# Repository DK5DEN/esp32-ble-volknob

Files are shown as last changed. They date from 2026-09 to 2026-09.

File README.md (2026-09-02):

# ESP32 BLE Volume Knob

A rotary knob based on the **ESP32-C3 Super Mini** that registers with an
Android phone over Bluetooth LE as an HID media keyboard ("VolKnob") and
controls the media volume.

- **Turn clockwise** → `KEY_MEDIA_VOLUME_UP`
- **Turn counter-clockwise** → `KEY_MEDIA_VOLUME_DOWN`
- **Press the button** → `KEY_MEDIA_MUTE`

No app is required on the phone; Android handles the HID consumer control
codes natively. The ESP32-C3 is powered over USB-C.

## Requirements

- ESP32-C3 Super Mini (or any other C3 board with native USB Serial/JTAG)
- **KY-040** rotary encoder with push-button (4 quadrature steps per detent)
- 5 wires; optionally 3× 10 nF for hardware debouncing and 1× 100 nF for
  supply decoupling
- [PlatformIO](https://platformio.org/) to build

## Wiring

| KY-040 | ESP32-C3 |
| --- | --- |
| CLK | GPIO1 |
| DT | GPIO3 |
| SW | GPIO4 |
| + | **3V3** |
| GND | GND |

**Why CLK goes to GPIO1 and not GPIO2.** The KY-040 header `CLK·DT·SW·+·GND`
lines up exactly with pads 2–6 of the right rail (GND, 3V3, GPIO4, GPIO3,
GPIO2), the only position where GND and 3V3 are adjacent and therefore the
only orientation that can be soldered on directly. That places CLK on GPIO2,
which is a strapping pin: if the knob rests between two detents at power-up,
the CLK contact pulls GPIO2 low and the board does not boot. A pull-up strong
enough to hold GPIO2 high at boot also makes the encoder signal unreadable in
normal operation, so CLK is wired to GPIO1 (pad 7) instead and GPIO2 is left
unused.

Also leave `GPIO9` (BOOT) and `GPIO8` (LED) unused.

**Supply from 3.3 V, not 5 V.** The 10 kΩ pull-ups of the KY-040 are tied to
the module's `+` pin, so a 5 V supply would put 5 V on the C3 GPIOs. Leave the
5V pin unconnected. The firmware still configures `INPUT_PULLUP` because not
every KY-040 variant has a module pull-up on `SW`.

**Keep the antenna clear.** The antenna of the Super Mini sits at the end
opposite the USB-C connector. Do not place the encoder board over it; doing so
reduces BLE range.

### Schematic

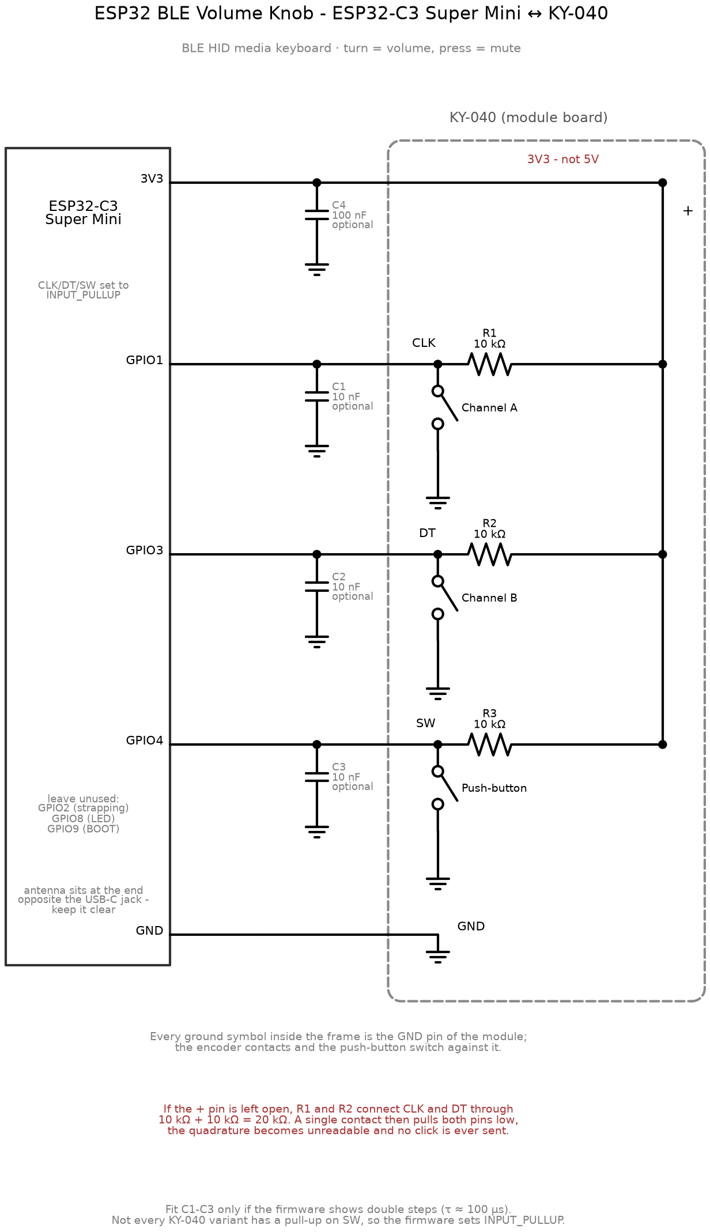
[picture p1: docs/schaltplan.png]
Schematic


The drawing also shows the internals of the KY-040 module board: R1–R3 are the
pull-ups **on the module**, tied to its `+` pin. The encoder contacts and the
push-button switch against the module's GND pin, which is why every ground
symbol inside the dashed frame is the same connection.

C1–C3 (10 nF) are optional hardware debouncing: build without them first and
only add them if the firmware shows double steps. Together with the 10 kΩ
module pull-up they give τ ≈ 100 µs. C4 (100 nF) decouples the module supply.

The drawing is generated from [`docs/schaltplan.py`](docs/schaltplan.py) using
[schemdraw](https://schemdraw.readthedocs.io/):

```bash
python docs/schaltplan.py     # writes docs/schaltplan.svg + .png
```

## Build and flash

```bash
pio run              # build
pio run -t upload    # flash
```

The C3 Super Mini enumerates as a serial port over USB Serial/JTAG
(VID `303A` / PID `1001`); no BOOT button is needed. The upload port can be
pinned down in `platformio.ini` if several boards are attached.

Footprint: roughly 500 kB of flash out of 3.1 MB (partition scheme `huge_app`)
and just under 24 kB of RAM.

The BLE HID layer comes from
[T-vK/ESP32-BLE-Keyboard](https://github.com/T-vK/ESP32-BLE-Keyboard) in its
**NimBLE flavour** (`-DUSE_NIMBLE`); the Bluedroid version quickly exceeds the
available flash on the C3.

## Pairing

Android → Bluetooth → select "VolKnob" → connect. No PIN.

## Troubleshooting

### Nothing happens even though the encoder turns mechanically

The most likely cause is that the **`+` wire (3V3) has no contact**. The
symptoms look like a firmware bug but are a wiring fault:

- CLK and DT always change *together*, only 1–2 µs apart in a microsecond
  trace, which is mechanically impossible.
- The quadrature table therefore sees the transition `11 → 00`, which is index
  3 and index 12, both `0`. Every step is discarded, `encDelta` stops moving,
  and no click is ever sent.
- On top of that, dozens of microsecond-scale edges appear per detent.

Reason: the two 10 kΩ pull-ups of the module are tied to the `+` node. If that
node floats, they connect CLK and DT through 10 k + 10 k = **20 kΩ**. When a
contact pulls CLK to ground, DT is dragged along through those 20 kΩ against
the C3's internal 45 kΩ pull-up:

```
U_DT = 3.3 V × 20k / (20k + 45k) ≈ 1.0 V   → below the logic threshold → reads 0
```

### Checking the module supply without a multimeter

Read the pin twice, once with the internal pull-up and once with the internal
pull-down:

```cpp
pinMode(pin, INPUT_PULLUP);   delayMicroseconds(500); int up   = digitalRead(pin);
pinMode(pin, INPUT_PULLDOWN); delayMicroseconds(500); int down = digitalRead(pin);
pinMode(pin, INPUT_PULLUP);
```

| pull-up | pull-down | meaning |
| --- | --- | --- |
| 1 | 1 | external pull-up present — module is connected to 3V3 |
| 1 | 0 | floating — **no** external pull-up |
| 0 | 0 | tied to ground — contact closed |

The internal pull-down is around 45 kΩ, so the 10 kΩ module pull-up wins
clearly against it. This shows whether the supply actually reaches the module
without needing a meter.

### Observing the events on the Android device

```bash
adb shell dumpsys bluetooth_manager | grep -A3 VolKnob   # bond state and Hogp profile
adb shell getevent -p | grep -A6 VolKnob                 # HID device, e.g. /dev/input/event8
adb shell settings get system volume_music               # 0..15
adb logcat -v time | grep "applyVolumeRow 3:"            # LEVEL/MUTED per change
```

Redirecting `getevent -lt` through `adb shell` into a file does not work; the
output is buffered and never arrives. `logcat` and `settings get` are the
reliable way.

### Other pitfalls

- **Verify the module pinout.** There are KY-040 variants with
  `GND·+·SW·DT·CLK` and other orders. With 3.3 V wired straight to the module,
  a swap is not forgiving.
- **Direction inverted:** swap `PIN_CLK` and `PIN_DT` in the code.
- **Double steps per detent:** set `DETENT_STEPS` to 2 or 1, depending on the
  detent scheme of the specific encoder.
- **Mute has no effect:** some Android versions ignore `KEY_MEDIA_MUTE` for the
  media stream. Fallback: track the volume on the ESP32, ramp it to 0 on the
  first press and back up on the second. On a Galaxy A16 (SM-A165F)
  `KEY_MEDIA_MUTE` works directly.
- **Reconnecting after the phone locks** takes a few seconds, which is normal
  for BLE.
- Turning while the phone is still establishing the connection has no effect;
  there is no wakelock.

## Tested with

ESP32-C3 Super Mini, KY-040, Samsung Galaxy A16 (SM-A165F): 5 detents
clockwise raise the media volume from 7 to 12, 5 detents back return it to 7,
one step per detent with no dropped clicks.

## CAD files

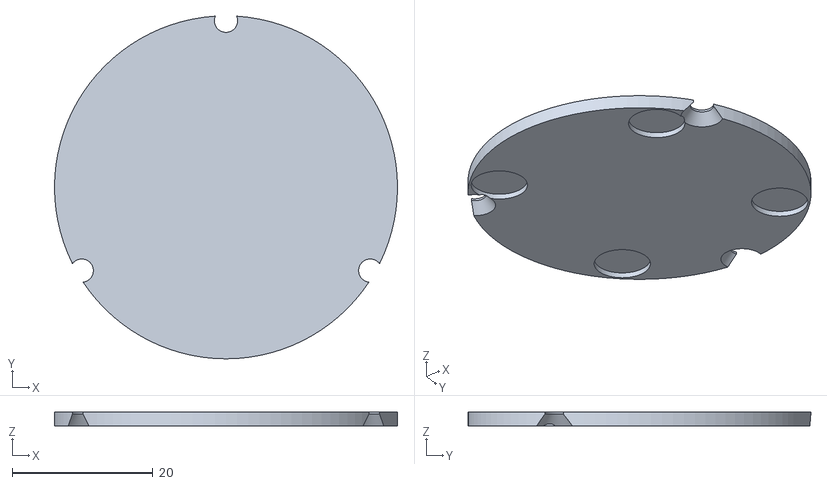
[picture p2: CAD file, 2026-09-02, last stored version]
case/plate.stl
48.8 x 48.7 x 2.00

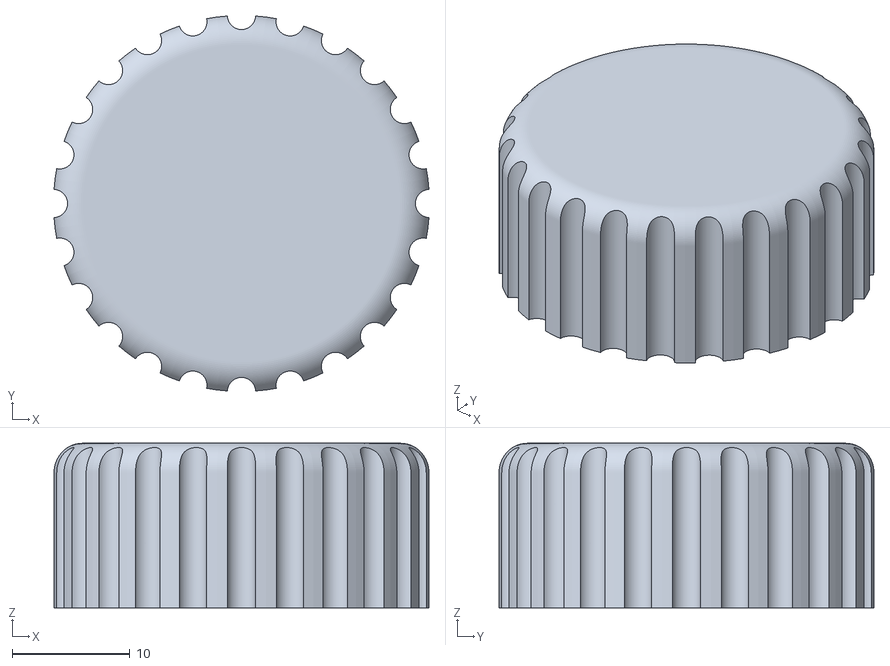
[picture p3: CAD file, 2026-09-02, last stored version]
case/knob.stl
31.9 x 31.9 x 14.0

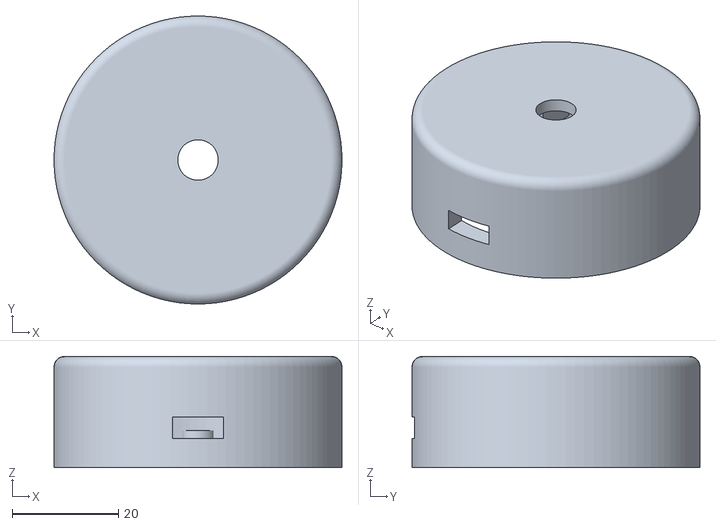
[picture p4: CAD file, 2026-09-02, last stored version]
case/body.stl
54.2 x 54.2 x 20.9

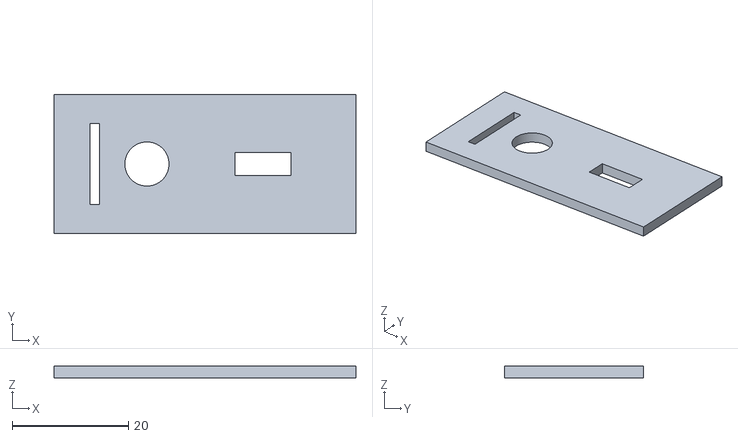
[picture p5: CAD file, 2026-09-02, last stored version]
case/fittest.stl
52.0 x 24.0 x 2.00

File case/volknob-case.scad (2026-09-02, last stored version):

// -----------------------------------------------------------------------------
// Enclosure for the ESP32 BLE Volume Knob (ESP32-C3 Super Mini + KY-040).
//
// Round desktop puck. The KY-040 is clamped by its own M7 bushing nut against
// the underside of the top face, four ribs keep the board from turning, the
// ESP32-C3 slides into a pair of rails, and a bottom plate closes the case with
// three M3 screws.
//
// Coordinate system: z = 0 is the INNER surface of the top face. The case grows
// upwards to +top_t and downwards to -(cavity_h + floor_t).
//
// Print settings assumed: FDM, 0.4 mm nozzle, 0.2 mm layers.
//   body   - print upside down, top face on the bed. No supports needed.
//   plate  - print flat.
//   knob   - print with the open side down. Optional, most KY-040 kits ship one.
//
// Export a single part with:
//   openscad -D part=\"body\" -o body.stl volknob-case.scad
//
// Every dimension below is nominal. Measure your own parts with calipers and
// print part="fittest" first - it carries the three critical fits and takes a
// few minutes.
// -----------------------------------------------------------------------------

part = "body";   // "body" | "plate" | "knob" | "fittest" | "assembly" | "section"

// --- measured part dimensions ------------------------------------------------
enc_pcb_x     = 19.0;   // KY-040 board, short edge
enc_pcb_y     = 26.0;   // KY-040 board, long edge
enc_pcb_t     = 1.6;    // KY-040 board thickness
enc_body_h    = 6.7;    // encoder body height, board surface to its top face
bushing_d     = 7.0;    // threaded bushing, M7 x 0.75
bushing_h     = 5.0;    // bushing length above the encoder body
nut_t         = 2.2;    // bushing nut thickness
shaft_d       = 6.0;    // shaft diameter
pin_len       = 3.2;    // header pins and solder joints below the board
// MEASURE THIS: distance from the shaft axis to the centre of the KY-040
// board, positive towards the pin header. On most boards the encoder sits at
// one end and the header at the other, so this is NOT zero. The fit test
// cannot catch it - check it before printing the body.
enc_off_y     = 6.0;

esp_pcb_x     = 18.0;   // ESP32-C3 Super Mini, short edge
esp_pcb_y     = 22.5;   // ESP32-C3 Super Mini, long edge
esp_pcb_t     = 1.0;    // board thickness
esp_top_clear = 3.6;    // clearance above the board for components
usb_w         = 9.0;    // USB-C receptacle width
usb_h         = 3.4;    // USB-C receptacle height above the board surface

// --- case --------------------------------------------------------------------
// The outer diameter follows from the boards; set case_d_min to force a larger
// puck. Everything else scales with it.
case_d_min    = 0;      // 0 = derive from the parts
wall          = 2.4;    // side wall
top_t         = 2.4;    // top face; must stay below bushing_h - nut_t
floor_t       = 2.0;    // bottom plate
clr           = 0.3;    // print clearance, per side
fillet        = 2.0;    // rounding of the top edge

screw_d       = 2.5;    // core hole for an M3 self-tapping screw
screw_head_d  = 6.0;    // countersink in the bottom plate
post_d        = 6.0;    // screw post diameter, merges into the side wall
post_h        = 5.0;    // post height above the seam
post_angles   = [90, 210, 330];   // chosen to clear both boards

foot_d        = 8.0;    // recess for a self-adhesive rubber foot
foot_depth    = 0.8;

rib_w         = 2.4;    // anti-rotation rib width

// --- derived stack, measured downwards from the inner top face ---------------
z_enc_pcb_top = -enc_body_h;                        // KY-040 board, top surface
z_enc_pcb_bot = z_enc_pcb_top - enc_pcb_t;
z_enc_pins    = z_enc_pcb_bot - pin_len;            // lowest point of the module
z_esp_top     = z_enc_pins - 1.5;                   // ESP32-C3, top of the board
z_esp_bot     = z_esp_top - esp_pcb_t;
cavity_h      = -z_esp_bot + 2.5;                   // seam sits below the board
total_h       = top_t + cavity_h + floor_t;

z_seam        = -cavity_h;                          // body/plate joint
ledge         = 1.5;                                // shoulder the plate rests on
rib_h         = enc_body_h + enc_pcb_t + 1.5;       // ribs run from the top face down

// Radius needed by each board, taken at its worst corner. The KY-040 usually
// decides, because the shaft is offset from the board centre by enc_off_y.
r_need_enc    = sqrt(pow(enc_pcb_x / 2 + clr + rib_w, 2) +
                     pow(abs(enc_off_y) + enc_pcb_y / 2, 2));
r_need_esp    = sqrt(pow(esp_pcb_x / 2 + clr + 2.4, 2) + pow(esp_pcb_y / 2, 2));

r_cavity      = max(r_need_enc, r_need_esp) + 0.6;
r_inner       = r_cavity + ledge;                   // bottom plate seat
case_d        = max(case_d_min, 2 * (r_inner + wall));

screw_circle  = r_cavity + 0.5;                     // posts merge into the wall
foot_circle   = case_d / 2 - 7.0;
// Push the ESP32-C3 against the wall so the USB-C receptacle reaches the
// opening. The wall is curved, so the usable chord at the board width decides.
esp_y_wall    = -sqrt(r_cavity * r_cavity - pow(esp_pcb_x / 2 + clr, 2));
esp_y_off     = esp_y_wall + esp_pcb_y / 2;

$fn = 96;

echo(str("stack: enc_pcb ", z_enc_pcb_top, "  pins ", z_enc_pins,
         "  esp ", z_esp_top, "  seam ", z_seam, "  total_h ", total_h));
echo(str("case_d ", case_d, "   r_cavity ", r_cavity,
         "   r_need_enc ", r_need_enc, "   r_need_esp ", r_need_esp));
echo(str("esp board y ", esp_y_off - esp_pcb_y / 2, " .. ", esp_y_off + esp_pcb_y / 2,
         "   ky040 board y ", enc_off_y - enc_pcb_y / 2, " .. ", enc_off_y + enc_pcb_y / 2,
         "   cavity r ", r_cavity));

// =============================================================================
// helpers
// =============================================================================

// Puck spanning z = 0..h with the top edge rounded by r.
module puck(d, h, r) {
    hull() {
        cylinder(d = d, h = h - r);
        translate([0, 0, h - r]) rotate_extrude() translate([d / 2 - r, 0])
            circle(r = r);
        translate([0, 0, h - r]) cylinder(d = d - 2 * r, h = r);
    }
}

// =============================================================================
// body
// =============================================================================
// The cavity has to be cut BEFORE the internal features are added, otherwise it
// removes them again.
module body() {
    difference() {
        union() {
            difference() {
                // outer shell
                translate([0, 0, -(cavity_h + floor_t)]) puck(case_d, total_h, fillet);

                // inner cavity; r_cavity leaves a shoulder for the bottom plate
                translate([0, 0, z_seam - 0.01])
                    cylinder(d = 2 * r_cavity, h = cavity_h + 0.02);

                // recess that takes the bottom plate
                translate([0, 0, -(cavity_h + floor_t) - 0.01])
                    cylinder(d = 2 * r_inner, h = floor_t + 0.01);
            }

            // anti-rotation ribs around the KY-040 board, two per long edge
            for (sx = [-1, 1], sy = [-1, 1])
                translate([sx * (enc_pcb_x / 2 + clr + rib_w / 2),
                           enc_off_y + sy * (enc_pcb_y / 4),
                           -rib_h / 2])
                    cube([rib_w, 8, rib_h], center = true);

            // rails for the ESP32-C3: a ledge below plus a lip above the board
            for (s = [-1, 1]) {
                translate([s * (esp_pcb_x / 2 + clr + 0.8), esp_y_off, z_esp_bot - 0.6])
                    cube([1.6, esp_pcb_y, 1.2], center = true);
                translate([s * (esp_pcb_x / 2 + clr + 0.8), esp_y_off, z_esp_top + 0.6])
                    cube([1.6, esp_pcb_y, 1.2], center = true);
            }

            // screw posts, merged into the side wall
            for (a = post_angles) rotate([0, 0, a])
                translate([screw_circle, 0, z_seam])
                    cylinder(d = post_d, h = post_h);
        }

        // ---- cut last, so nothing added above can block these -----------------
        // bushing hole through the top face
        translate([0, 0, -0.01])
            cylinder(d = bushing_d + 2 * clr, h = top_t + 0.02);

        // USB-C opening through the wall at -y
        translate([-(usb_w / 2 + clr), -case_d / 2 - wall, z_esp_top])
            cube([usb_w + 2 * clr, 3 * wall, usb_h + 2 * clr]);

        // screw holes
        for (a = post_angles) rotate([0, 0, a])
            translate([screw_circle, 0, z_seam - 0.01])
                cylinder(d = screw_d, h = post_h + 0.02);
    }
}

// =============================================================================
// bottom plate
// =============================================================================
module plate() {
    difference() {
        cylinder(d = 2 * r_inner - 2 * clr, h = floor_t);
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

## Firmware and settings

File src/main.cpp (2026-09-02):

#include <Arduino.h>
#include <BleKeyboard.h>

#define PIN_CLK 1
#define PIN_DT  3
#define PIN_SW  4

#define DETENT_STEPS 4      // KY-040: 4 quadrature steps per click
#define BTN_DEBOUNCE 50     // ms

BleKeyboard bleKeyboard("VolKnob", "DIY", 100);

volatile int8_t  encDelta = 0;
volatile uint8_t encState = 0;

// quadrature state machine lookup
const int8_t encTable[16] = { 0,-1, 1, 0,
                              1, 0, 0,-1,
                             -1, 0, 0, 1,
                              0, 1,-1, 0 };

void IRAM_ATTR encISR() {
  encState = ((encState << 2) |
              (digitalRead(PIN_CLK) << 1) |
               digitalRead(PIN_DT)) & 0x0F;
  encDelta += encTable[encState];
}

void setup() {
  pinMode(PIN_CLK, INPUT_PULLUP);
  pinMode(PIN_DT,  INPUT_PULLUP);
  pinMode(PIN_SW,  INPUT_PULLUP);

  // Seed the state machine from the actual pin levels. Starting encState at 00
  // while the idle pins sit at 11 makes the first edge land on table index 3
  // (= 0), which loses one quadrature step and swallows a click on every
  // change of direction.
  encState = (digitalRead(PIN_CLK) << 1) | digitalRead(PIN_DT);

  attachInterrupt(PIN_CLK, encISR, CHANGE);
  attachInterrupt(PIN_DT,  encISR, CHANGE);

  bleKeyboard.begin();
}

void loop() {
  if (!bleKeyboard.isConnected()) { delay(100); return; }

  // --- rotation ---
  noInterrupts();
  int8_t d = encDelta;
  if (d >= DETENT_STEPS || d <= -DETENT_STEPS) {
    encDelta -= (d / DETENT_STEPS) * DETENT_STEPS;
  } else {
    d = 0;
  }
  interrupts();

  int clicks = d / DETENT_STEPS;
  while (clicks > 0)  { bleKeyboard.write(KEY_MEDIA_VOLUME_UP);   clicks--; delay(15); }
  while (clicks < 0)  { bleKeyboard.write(KEY_MEDIA_VOLUME_DOWN); clicks++; delay(15); }

  // --- button ---
  static bool     lastState = HIGH;
  static uint32_t lastEdge  = 0;
  bool now = digitalRead(PIN_SW);

  if (now != lastState && millis() - lastEdge > BTN_DEBOUNCE) {
    lastEdge  = millis();
    lastState = now;
    if (now == LOW) bleKeyboard.write(KEY_MEDIA_MUTE);
  }

  delay(2);
}

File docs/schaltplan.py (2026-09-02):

"""
Schematic for the ESP32 BLE Volume Knob - ESP32-C3 Super Mini <-> KY-040.
Writes docs/schaltplan.svg and docs/schaltplan.png:  python docs/schaltplan.py

Both files are saved with an opaque white background so they stay readable on
hosts that render them against a dark page, such as GitHub in dark mode.
"""
import schemdraw
import schemdraw.elements as elm

schemdraw.config(font='sans-serif', fontsize=11)

# --- grid -------------------------------------------------------------------
X_ESP_L, X_ESP_R = -5.4, -1.6   # board outline
X_LEAD = 0.4                    # end of the pin leads
X_CAP = 1.8                     # optional capacitors
X_NODE = 4.6                    # signal node inside the module
X_BUS = 9.8                     # module + rail (vertical)

Y_VCC = 4.2                     # 3V3 line
Y_GND = -13.2                   # GND line
Y_TOP, Y_BOT = 5.0, -13.9       # board outline edges

# (module pin, GPIO, contact, C designator, R designator, y)
ROWS = [
    ('CLK', 'GPIO1', 'Channel A',  'C1', 'R1', 0.0),
    ('DT',  'GPIO3', 'Channel B',  'C2', 'R2', -4.4),
    ('SW',  'GPIO4', 'Push-button', 'C3', 'R3', -8.8),
]

with schemdraw.Drawing(show=False) as d:
    d.config(unit=2.0)

    # =====================================================================
    # Title
    # =====================================================================
    d += elm.Label().at((2.5, Y_TOP + 3.0)).label(
        'ESP32 BLE Volume Knob - ESP32-C3 Super Mini ↔ KY-040', fontsize=15)
    d += elm.Label().at((2.5, Y_TOP + 2.2)).label(
        'BLE HID media keyboard · turn = volume, press = mute',
        fontsize=10, color='gray')

    # =====================================================================
    # ESP32-C3 Super Mini outline with pin leads
    # =====================================================================
    for a, b in (((X_ESP_L, Y_TOP), (X_ESP_R, Y_TOP)),
                 ((X_ESP_R, Y_TOP), (X_ESP_R, Y_BOT)),
                 ((X_ESP_R, Y_BOT), (X_ESP_L, Y_BOT)),
                 ((X_ESP_L, Y_BOT), (X_ESP_L, Y_TOP))):
        d += elm.Line().at(a).to(b).color('#333')

    d += elm.Label().at(((X_ESP_L + X_ESP_R) / 2, Y_TOP - 1.6)).label(
        'ESP32-C3\nSuper Mini', fontsize=12)
    d += elm.Label().at(((X_ESP_L + X_ESP_R) / 2, Y_TOP - 3.4)).label(
        'CLK/DT/SW set to\nINPUT_PULLUP', fontsize=8.5, color='gray')
    d += elm.Label().at(((X_ESP_L + X_ESP_R) / 2, Y_BOT + 3.4)).label(
        'leave unused:\nGPIO2 (strapping)\nGPIO8 (LED)\nGPIO9 (BOOT)',
        fontsize=8.5, color='gray')
    d += elm.Label().at(((X_ESP_L + X_ESP_R) / 2, Y_BOT + 1.4)).label(
        'antenna sits at the end\nopposite the USB-C jack -\nkeep it clear',
        fontsize=8.5, color='gray')

    def pin(y, name):
        d.add(elm.Line().at((X_ESP_R, y)).to((X_LEAD, y)))
        d.add(elm.Label().at((X_ESP_R - 0.25, y)).label(name, fontsize=10, halign='right'))

    pin(Y_VCC, '3V3')
    for modpin, gpio, contact, cref, rref, y in ROWS:
        pin(y, gpio)
    pin(Y_GND, 'GND')

    # =====================================================================
    # 3V3: run to the right, decoupling cap, then the vertical + rail
    # =====================================================================
    d += elm.Line().at((X_LEAD, Y_VCC)).to((X_BUS, Y_VCC))
    d += elm.Label().at((X_BUS - 2.4, Y_VCC + 0.45)).label(
        '3V3 - not 5V', fontsize=9.5, color='#a33')

    d += elm.Dot().at((X_CAP, Y_VCC))
    d += elm.Capacitor().down().at((X_CAP, Y_VCC)).length(1.5).label(
        'C4\n100 nF\noptional', loc='bottom', fontsize=8.5, color='gray')
    d += elm.Ground()

    bus_top = d.add(elm.Dot().at((X_BUS, Y_VCC)))
    d += elm.Line().at((X_BUS, Y_VCC)).to((X_BUS, ROWS[-1][5]))
    d += elm.Label().at((X_BUS + 0.35, Y_VCC - 0.55)).label('+', fontsize=12, halign='left')

    # =====================================================================
    # GND: run to the module, reference ground there
    # =====================================================================
    d += elm.Line().at((X_LEAD, Y_GND)).to((X_NODE, Y_GND))
    gnd_mod = d.add(elm.Ground().at((X_NODE, Y_GND)))
    d += elm.Label().at((X_NODE + 0.35, Y_GND + 0.1)).label(
        'GND', fontsize=10, halign='left')

    # =====================================================================
    # The three signal branches
    # =====================================================================
    box = [bus_top, gnd_mod]

    for modpin, gpio, contact, cref, rref, y in ROWS:
        # optional debounce cap on the wire to the module
        d += elm.Line().at((X_LEAD, y)).to((X_CAP, y))
        cnode = d.add(elm.Dot().at((X_CAP, y)))
        d += elm.Capacitor().down().at((X_CAP, y)).length(1.5).label(
            cref + '\n10 nF\noptional', loc='bottom', fontsize=8.5, color='gray')
        d += elm.Ground()
        d += elm.Line().at(cnode.center).to((X_NODE, y))

        node = d.add(elm.Dot().at((X_NODE, y)))
        box.append(node)
        d += elm.Label().at((X_NODE - 0.15, y + 0.4)).label(
            modpin, fontsize=10, halign='right')

        # module pull-up to + (horizontal, into the rail)
        r = elm.Resistor().right().at((X_NODE, y)).length(2.4).label(
            rref + '\n10 kΩ', fontsize=9)
        d += r
        box.append(r)
        d += elm.Line().to((X_BUS, y))
        box.append(d.add(elm.Dot().at((X_BUS, y))))

        # contact to ground (vertical, downwards)
        sw = elm.Switch().down().at((X_NODE, y)).length(2.0).label(
            contact, loc='bottom', fontsize=9)
        d += sw
        box.append(sw)
        d += elm.Line().down().length(0.7)
        box.append(d.add(elm.Ground()))

    # =====================================================================
    # Module outline
    # =====================================================================
    d += elm.EncircleBox(box, padx=0.9, pady=0.9).linestyle('--').color('#888')
    d += elm.Label().at((X_NODE + 2.0, Y_VCC + 1.6)).label(
        'KY-040 (module board)', fontsize=11.5, color='#555')
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

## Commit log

2026-09-02 feat: BLE-Media-Knob auf ESP32-C3 mit KY-040
    Drehregler, der sich per BLE als HID-Consumer-Control-Geraet am Handy
    anmeldet: Drehen steuert die Medienlautstaerke, Druecken schaltet stumm.
    Quadratur wird per Zustandstabelle im ISR dekodiert. encState wird aus den
    echten Pegeln initialisiert -- startet er auf 00, waehrend die Pins in Ruhe
    auf 11 liegen, faellt die erste Flanke auf Tabellenindex 3 (= 0) und ein
    Quadraturschritt geht verloren. Das verschluckt bei jedem Richtungswechsel
    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
2026-09-02 docs: Schaltplan statt Steckbrettplan
    Gebaut wurde fliegend verdrahtet, nicht auf dem Steckbrett. Der Schaltplan
    zeigt zusaetzlich das Innenleben der KY-040-Modulplatine -- R1/R2 am
    +-Pin sind der Grund, warum eine offene +-Ader die Quadratur unlesbar macht
    und wie ein Firmware-Bug aussieht.
    Gezeichnet mit schemdraw, Quelle in docs/schaltplan.py, analog zu
    docs/schaltplan.py im qo100-pa-ctrl-Repo. Der Steckbrettplan bleibt als
    Planungsstand erhalten, ist aber als nicht gebaut gekennzeichnet.
    [schaltplan.py]
2026-09-02 docs: switch documentation to English, opaque schematic background
    README, code comments and schematic labels are now English.
    The schematic is saved with transparent=False so the PNG and SVG carry an
    opaque white background; the transparent default was unreadable on hosts that
    render it against a dark page.
    Corrections: the antenna sits at the end opposite the USB-C jack, not at the
    USB-C end. Dropped the breadboard plan, which was never built, together with
    its alternate pin assignment.
    [main.cpp, schaltplan.py]
2026-09-02 feat: parametric enclosure for the knob
    Round desktop puck, OpenSCAD source plus exported STLs. The KY-040 is clamped
    by its own M7 bushing nut against the top face and held against rotation by
    four ribs, the ESP32-C3 slides into rails that push it against the wall so the
    USB-C receptacle reaches the opening, and a bottom plate closes it with three
    M3 screws.
    The outer diameter is derived from the board dimensions rather than fixed, so
    correcting a measurement re-sizes the case. Defaults give a puck of
    54.2 x 20.9 mm.
    Also adds a fit-test coupon carrying the bushing hole, the USB-C opening and a
    board-thickness slot, so the clearances can be checked in a few minutes instead
    of after a full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
    [body.stl, fittest.stl, knob.stl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]
2026-09-02 Revert "feat: parametric enclosure for the knob"
    This reverts commit 8782749bf893f951ab55ab1a4e12f35a05e1069d.
    [body.stl, fittest.stl, knob.stl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]
